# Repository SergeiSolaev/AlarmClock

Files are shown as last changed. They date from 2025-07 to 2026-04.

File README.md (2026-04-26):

<h1 align="center"> Часы-будильник</h1>
<p align="center">
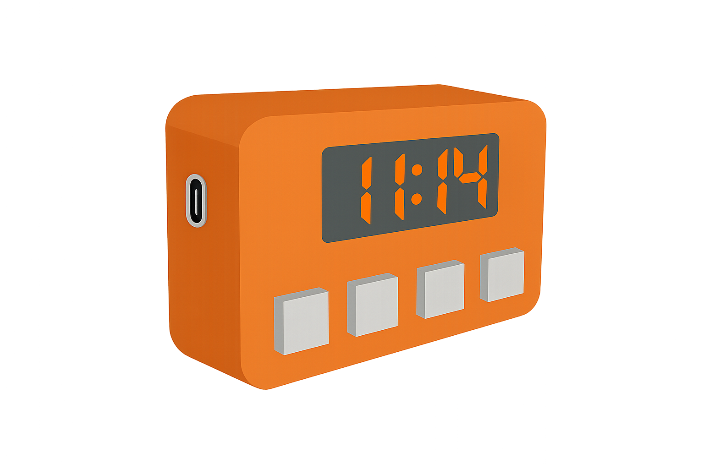
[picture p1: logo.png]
  
</p>
<p align="center">
  
</p>

## Описание проекта

Данный проект представляет собой автономный **умный будильник** на базе **Atmega328P-AU**, оснащённый модулем реального времени **DS3231**, MP3‑плеером **DFPlayer Mini**, семисегментным индикатором **TM1637**, вибромотором и системой энергосбережения. Устройство рассчитано на работу от аккумулятора и может использоваться как настольный или переносной будильник.

Проект ориентирован на низкое энергопотребление, удобное управление кнопками и расширенный функционал: музыка, вибрация, отложенный сигнал, индикация напряжения батареи и автоматическая регулировка яркости.

## ПО использованное при создании проекта
В проекте использовал следующее ПО:
- проектирование печатной платы `EasyEDA`
- проектирование корпуса `FreeCAD`
- написание кода `VSCode`, язык `Arduino C`
---

## Основные возможности

* Отображение текущего времени (RTC DS3231)
* Отображение даты и температуры
* Настраиваемый будильник
* Режим «Вздремнуть» (откладывание будильника)
* Таймер обратного отсчёта
* Звуковой сигнал (MP3) + вибрация
* Проигрывание музыки
* Регулировка громкости
* Автоматическая регулировка яркости по датчику освещённости
* Контроль напряжения аккумулятора
* Индикация разряда батареи
* Режим глубокого сна для экономии энергии
* Встроенный фонарик (LED)

---

## Аппаратная часть

### Основные компоненты

* **ATmega328P-AU** - микроконтроллер
* **RTC DS3231** — модуль реального времени
* **TM1637** — 4‑разрядный семисегментный индикатор
* **DFPlayer Mini** — MP3‑плеер для сигнала будильника и музыки
* **Вибромотор**
* **Светодиод** — режим фонарика
* **Фоторезистор** — датчик освещённости
* **Кнопки управления (4 шт.)**
* **Li‑Ion / Li‑Po аккумулятор**

### Питание и зарядка

Питание устройства осуществляется от аккумулятора.

*  Используется модуль **TP4056**
* Зарядка через разъём **USB Type‑C**
* Возможность одновременной зарядки и работы устройства

---

## Управление кнопками

| Кнопка | Действие |
| --- | --- |
| BTN1 | Вход / выход из меню, остановка будильника, выход из режима сна
| BTN2 | Показ температуры и даты. Подтверждение, сон (долгое нажатие) 
| BTN3 | Показ напряжения, отложить сигнал, уменьшение значений |
| BTN4 | Фонарик, отложить сигнал, увеличение значений |

---

## Меню

Меню вызывается коротким нажатием **BTN1**:

* **CLO** — установка времени
* **ALr** — включение / настройка будильника
* **LOUd** — установка громкости будильника
* **PLAY** — режим музыкального плеера
* **Chro** — таймер обратного отсчёта

Навигация осуществляется кнопкой **BTN4**, подтверждение — **BTN2**.

---

## Энергосбережение

* Отключение неиспользуемых периферийных модулей MCU
* Глубокий сон (**POWERDOWN_SLEEP**)
* Пробуждение по кнопке или сигналу RTC 

---

## Используемые библиотеки

* `RTClib`
* `DFPlayerMini_Fast`
* `GyverTM1637`
* `GyverPower`
* `EncButton`
* `EEPROM`

---

## Примечания

* Перед использованием рекомендуется откалибровать измерение напряжения батареи (см. комментарии в функции `voltageMeasure()`)
* Для установки времени с компьютера необходимо раскомментировать строку установки RTC в `setup()`
* Инструкцию по загрузке mp3 файлов на карту памяти см. в [/mp3/README.md](./mp3/README.md)

---

## Проектные файлы
### 3D модели корпуса
- [3d модель для FreeCAD](./free_cad/enclosure.FCStd)
- [Основной корпус](./free_cad/box.stl)
- [Крышка](./free_cad/lid.stl)

### Файлы печатной платы
- [Схема принципиальная](./easy_eda/Alarm_clock.json)
- [Разводка платы](./easy_eda/PCB_Alarm_clock.json)

## Фотографии проекта
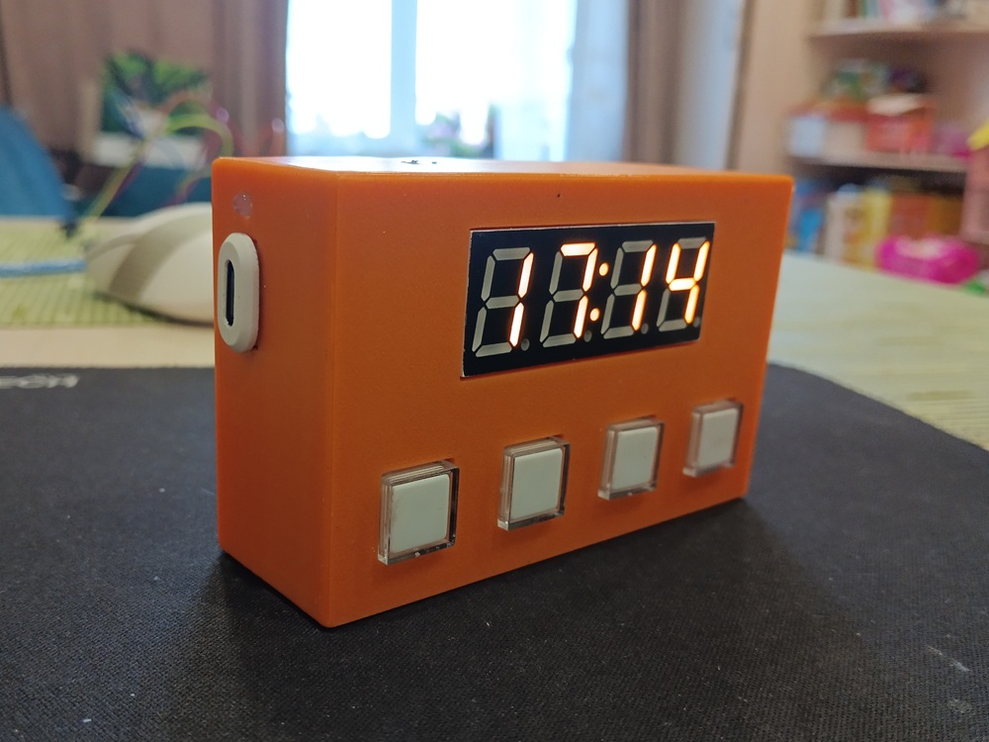
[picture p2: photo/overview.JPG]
Общий вид будильника
   
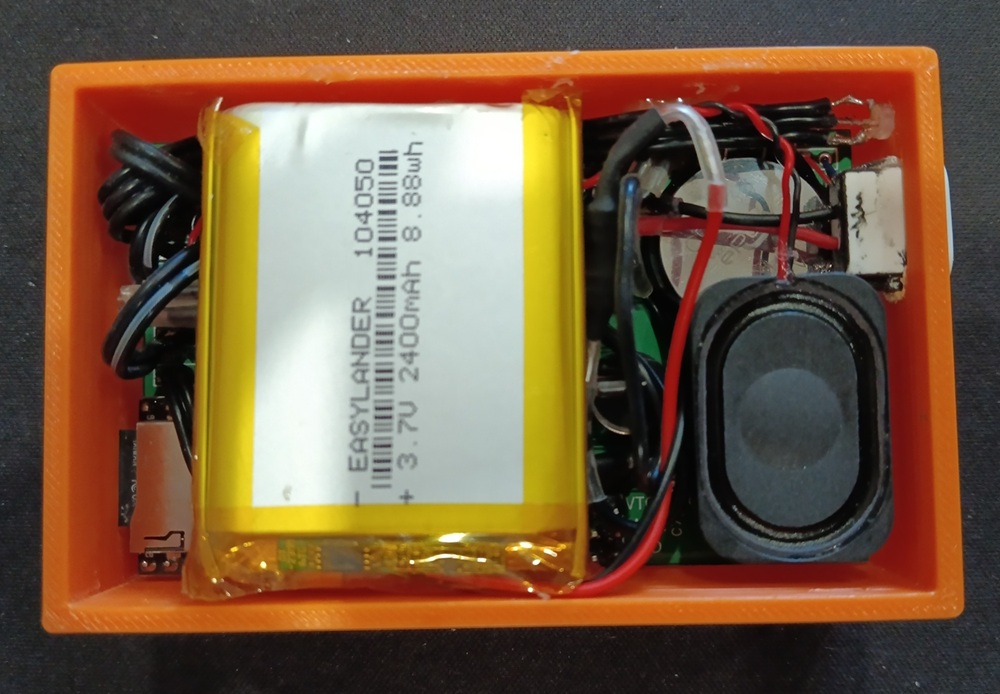
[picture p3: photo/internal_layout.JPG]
Внутренняя компоновка
   
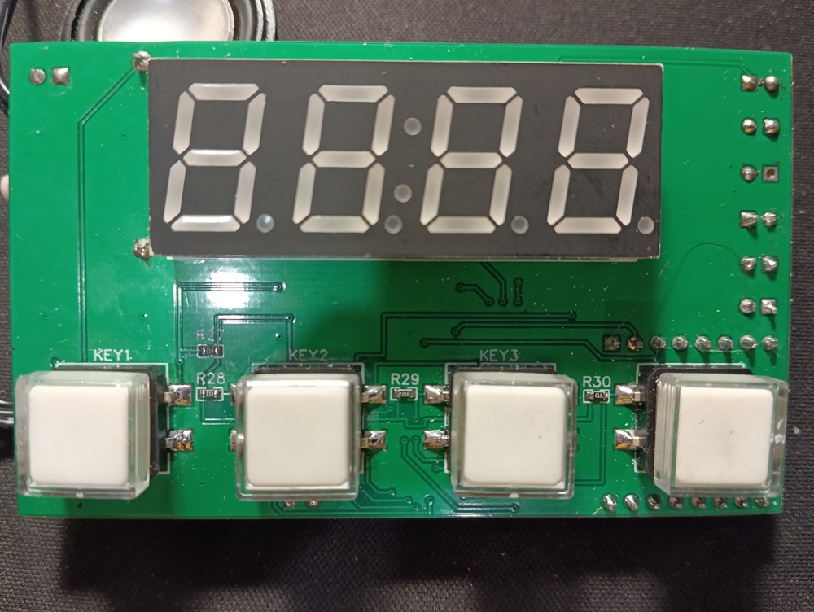
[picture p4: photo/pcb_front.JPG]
Плата будильника спереди
   
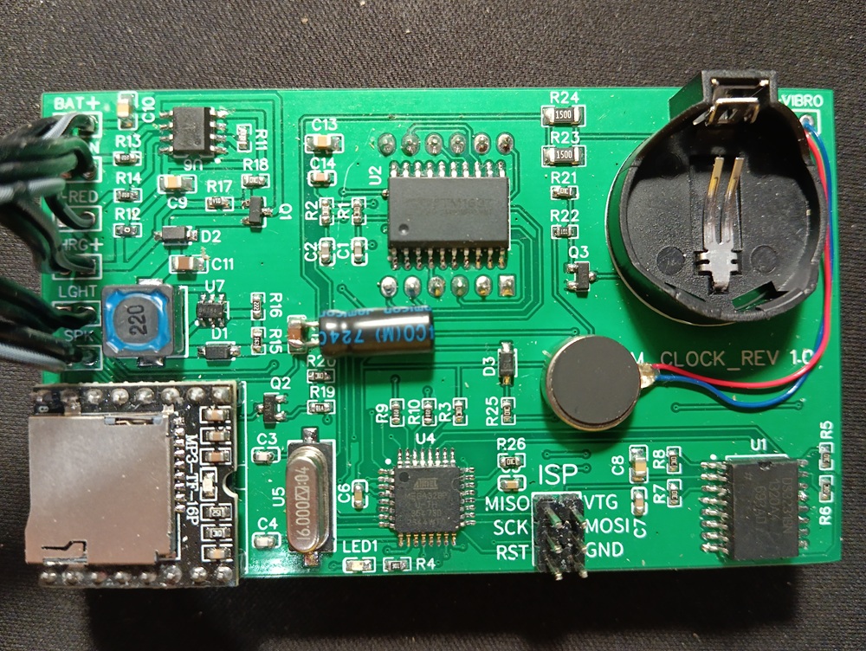
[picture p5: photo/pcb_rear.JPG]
Плата будильника сзади
 
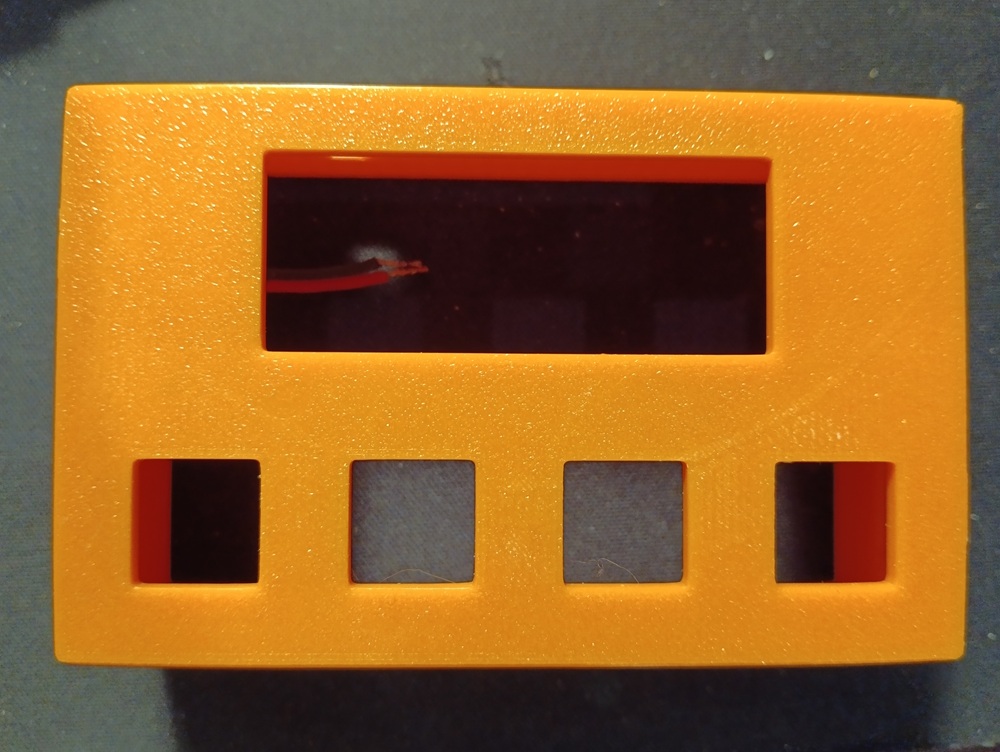
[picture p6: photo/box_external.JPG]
Корпус снаружи
   
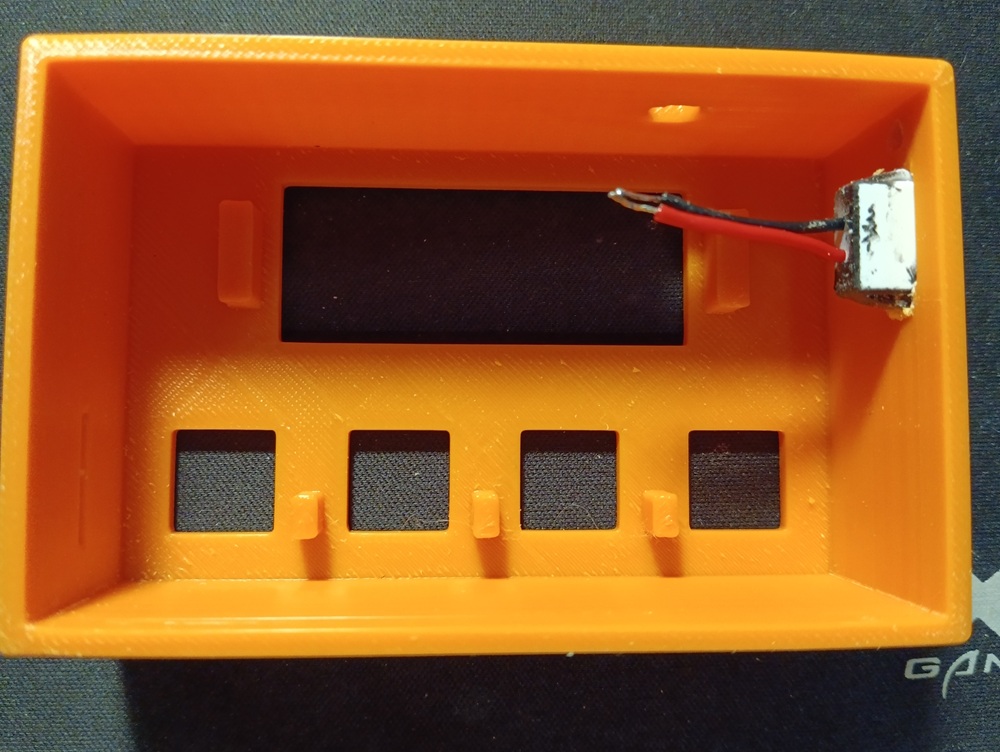
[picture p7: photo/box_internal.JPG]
Корпус внутри
   
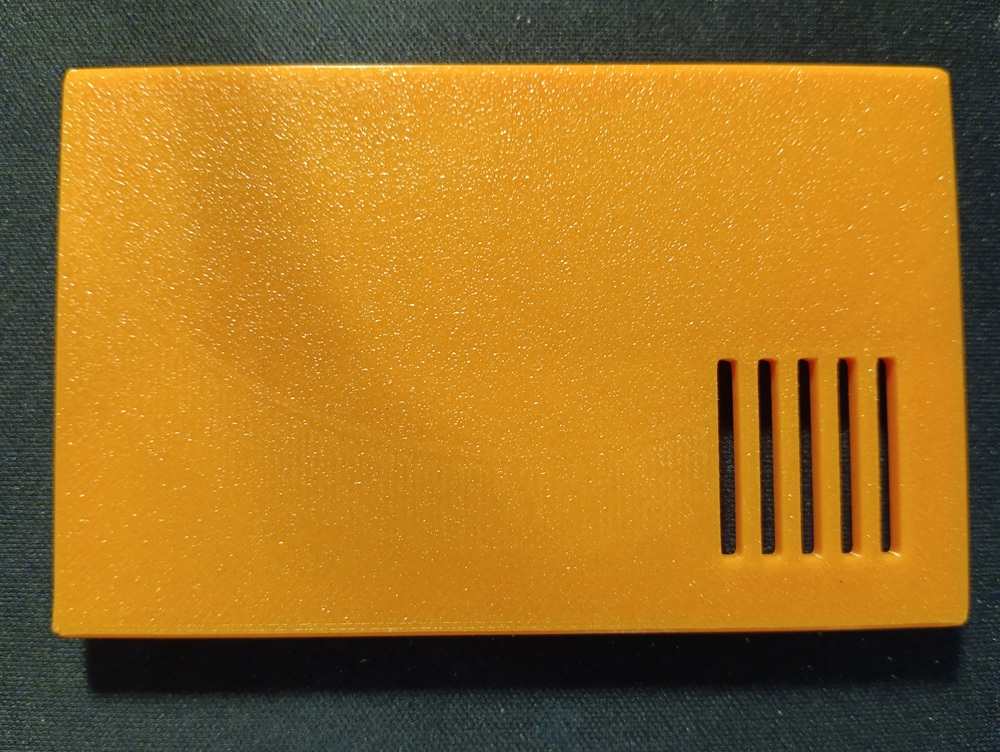
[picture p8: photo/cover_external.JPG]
Крышка снаружи
   
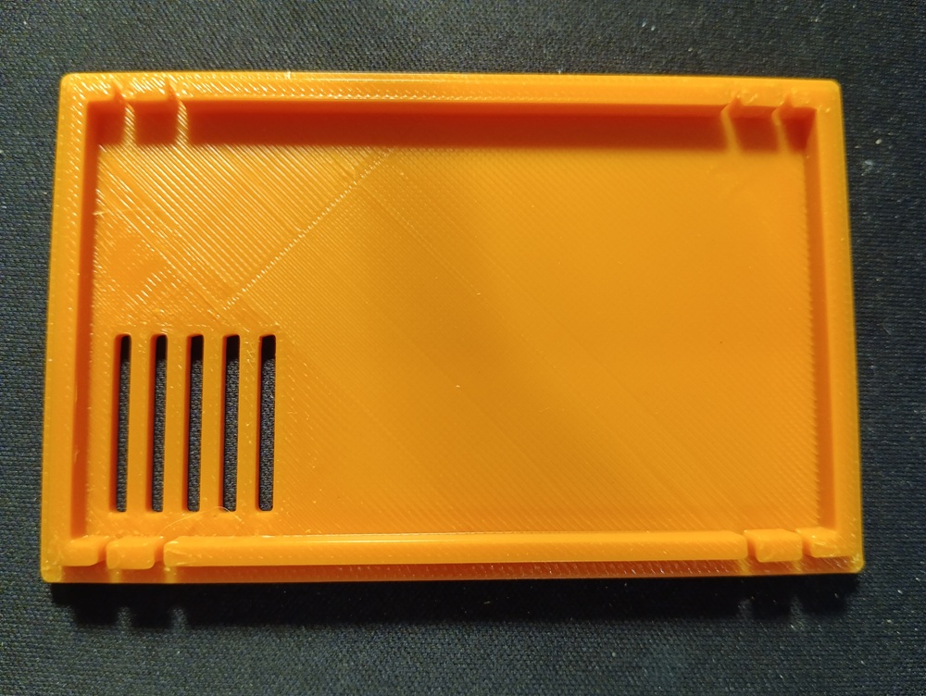
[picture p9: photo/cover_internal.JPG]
Крышка внутри
   

> Все файлы доступны в репозитории проекта. Для 3D печати рекомендуется использовать ABS пластик. Для загрузки скетча в микроконтроллер используется внутрисхемное программирвание. 

## Лицензия

Проект распространяется свободно и может быть использован, изменён и дополнен в учебных и личных целях.

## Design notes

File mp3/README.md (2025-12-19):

# Инструкция по загрузке аудиофайлов 

## Описание папки с аудиофайлами для DF Player Mini

В этой папке хранятся MP3-файлы, предназначенные для загрузки на карту памяти модуля воспроизведения музыки **DF Player Mini**

## Требования к файлам и карте памяти

- **Файловая система**:  
  Карта памяти должна быть отформатирована в **FAT16** или **FAT32**.

- **Имена файлов**:  
  Файлы должны быть названы в формате `0001.mp3`, `0002.mp3` и так далее.  

- **Расположение файлов**:  
  Все аудиофайлы должны быть загружены в папку `01` на карте памяти. Максимальное число файлов в папке `255`.

## Файл сигнала разряда батареи (отключено в v1.0.0)

В папке проекта находится файл:  
`0009_Battery_Discharge.mp3`  

Этот файл используется для воспроизведения сигнала при разрядке батареи.

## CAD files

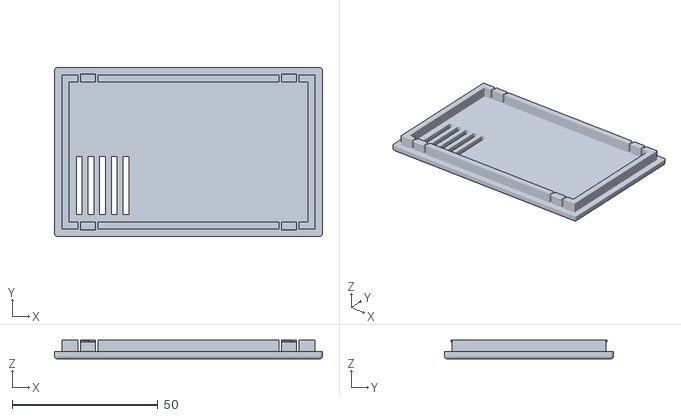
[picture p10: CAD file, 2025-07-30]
free_cad/lid.stl
92.0 x 58.0 x 6.50

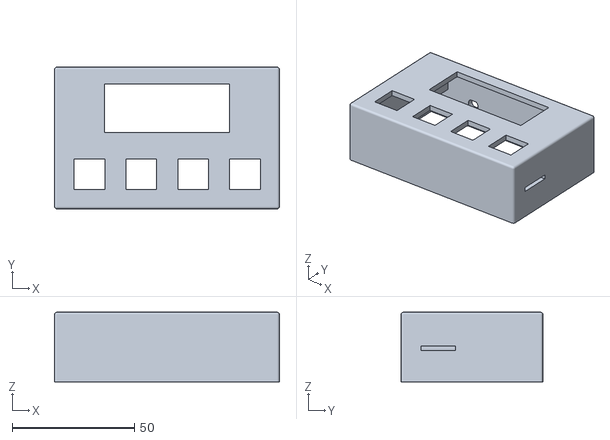
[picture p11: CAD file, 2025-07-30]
free_cad/box.stl
92.0 x 58.0 x 28.5

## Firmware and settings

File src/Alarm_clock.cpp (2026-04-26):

#include "Arduino.h"
#include "EEPROM.h"
#include "math.h"
#include "DFPlayerMini_Fast.h"
#include "RTClib.h"
#include "GyverTM1637.h"
#include "GyverPower.h"
#include "EncButton.h"

#define FW_VERSION "1.5.2"

// ===== HARDWARE =====

// Пины
#define BTN_1 2 // Pulup подтяжка(к "+" питания), когда нажата возвращает 0
#define BTN_2 10
#define BTN_3 4
#define BTN_4 5
#define CLK 6 // Подключение индикатора TM1637
#define DIO 7 // Подключение индикатора TM1637
#define VIBRO 8
#define MUSIC_MOSFET 9
#define LED 13
#define LIGHT_SENSOR A0
#define VOLTAGE A1

// Создаем объекты устройств
DFPlayerMini_Fast myMP3;
RTC_DS3231 rtc; // RTC DS3231 подключается к SDA – A4, SCL – A5
GyverTM1637 disp(CLK, DIO);

// Создаем объекты кнопок
Button btn1(BTN_1, INPUT_PULLUP, LOW);
Button btn2(BTN_2, INPUT_PULLUP, LOW);
Button btn3(BTN_3, INPUT_PULLUP, LOW);
Button btn4(BTN_4, INPUT_PULLUP, LOW);

// ===== SYSTEM TIMERS =====

uint32_t displayClockTimer;
uint32_t updateTimeTimer;
uint32_t vibroToggleTimer;
uint32_t batteryControlTimer;
uint32_t brightnessControlTimer;
uint32_t unblockMenuTimer;
uint32_t playMusicDisplayOfTimer;

// ===== CLOCK =====

bool clockOn = true;
bool secondsDots = false;

uint16_t year;
uint8_t month;
uint8_t day;
uint8_t hrs;
uint8_t min;
uint8_t sec;

// ===== ALARM =====

bool alarmOn = false; // Определяет включена ли функция будильньика
bool alarmOnDefault = false;
bool alarmSignal = false;
bool alarmMenuState = false;
bool alarmTriggered = false;
bool snoozeActive = false;

uint32_t alarmStartTime;
uint32_t alarmDuration = 60000;

uint8_t alarmHrs;
uint8_t alarmMin;
uint8_t alarmVolume;

uint8_t snoozeCount;
uint32_t snoozeStartTime;
uint32_t snoozeDuration = 300000;

// значения по умолчанию
uint8_t alarmHrsDefault = 12;
uint8_t alarmMinDefault = 0;
uint8_t alarmVolumeDefault = 20;

// ===== COUNTDOWN TIMER =====

bool timerActive = false;
bool timerFinished = false;
bool displayBlinking = false;
bool timerDisplayState = true;
bool timerInitialized = false;

uint32_t timerStartValue;    // начальное значение таймера в миллисекундах
uint32_t timerCurrentRemain; // оставшееся время
uint32_t timerPrevUpdate;    // время последнего обновления
uint32_t displayToggleTimer; // таймер для мигания дисплеем

// Значение таймера по умолчанию
uint32_t timerMinuteSet = 00;
uint32_t timerSecondSet = 00;

// ===== SIGNAL DEVICES =====

bool vibroToggle = true;
bool flashLightOn = false;
bool isPlaying = false;

// ===== POWER / BATTERY =====

bool batteryDischarge;

// ===== BRIGHTNESS CONTROL =====

int8_t currentBrightnessLevel = -1;

// ===== DISPLAY =====

// Преобразование символа цифры в код сегмента для передачи символа в функцию вывода на дисплей
// для показа версии
#define DIGIT_TO_SEG(x)              \
  ((x) == '0' ? _0 : (x) == '1' ? _1 \
                 : (x) == '2'   ? _2 \
                 : (x) == '3'   ? _3 \
                 : (x) == '4'   ? _4 \
                 : (x) == '5'   ? _5 \
                 : (x) == '6'   ? _6 \
                 : (x) == '7'   ? _7 \
                 : (x) == '8'   ? _8 \
                                : _9)

// Версия прошивки для показа
uint8_t fw_version[] = {
    _F,
    DIGIT_TO_SEG(FW_VERSION[0]),
    DIGIT_TO_SEG(FW_VERSION[2]),
    DIGIT_TO_SEG(FW_VERSION[4])};
// Сообщение "Зарядите батарею"
uint8_t chargeBattery[] = {_C, _H, _A, _r, _G, _E, _empty, _b, _A, _t, _t, _E, _r, _Y};

// ===== MAIN MENU =====
bool buttonsBlocked = false;
bool justWoke = false;
bool justWokeBlockMenu = false;
bool menuActive = false;
bool mainMenuActive = false;
int8_t mainMenuItem = 0;

// ===== SET TIME MENU =====
uint8_t clockMinTmp;
uint8_t clockHrsTmp;
uint8_t clockDate;
uint8_t clockMonth;
int clockYear;
bool setTimeMenuActive = false;
bool setTimeMenuDateTimeUpdate = false;
uint8_t setTimeStage = 0;

// ===== ALARM ON/OFF MENU =====
bool alarmOnOffMenuActive = false;

// ===== SET ALARM MENU =====
bool setAlarmDateTimeUpdated;
bool setAlarmActive;

uint8_t alarmHrsTmp;
uint8_t alarmMinTmp;

// ===== SET TIMER MENU =====
bool setTimerInitialized = false;
bool setTimerActive = false;
int timerMinuteSetTmp;
int timerSecondSetTmp;

// ===== SET VOLUME MENU =====
bool setVolumeActive = false;
bool setVolumeInitialized = false;
uint8_t setVolumeTmp;
uint32_t setVolTimer;

// ===== PLAY MUSIC MENU =====
bool playMusicMenuActive = false;
int8_t playMusicMenuItem = 0;

// ===== SET VOLUME MUSIC =====
bool setVolumeMusicActive = false;
bool setVolumeMusicInitialized = false;
uint8_t currentMusicVolume = 20;
uint8_t setVolumeMusicTmp;

//     BUTTON HOLD CHANGING
uint32_t lastHourChangeTime = 0;
uint32_t lastMinuteChangeTime = 0;
uint16_t INITIAL_DELAY = 500;   // Начальная задержка перед первым изменением
uint16_t CHANGE_INTERVAL = 500; // Интервал между изменениями

// ===== Прототипы функций =====
void initializeClock();
void pinsConfig();
void powerConfig();
void buttonConfig();
void testVibro();
void enterSleepMode();
void wakeUp();
void updateButtons();
void updateDateTime();
void displayClock(byte hrs, byte min);
void onAlarmInterrupt();
void activateAlarm();
void snoozeButton();
void alarmStopButton();
void alarmStopTime();
void runCountDownTimer();
void brightnessControl();
double voltageMeasure();
void showVoltage(double voltage);
void batteryControl(double voltage);
void showDate();
void startAlarm();
void stopAlarm();
void startVibro();
void stopVibro();
void menu();
void alarmOnOffMenu();
void setAlarm();
void setTime();
void setTimer();
void setVolume();
void playMusicMenu();
void playMusic();
void previousTrack();
void nextTrack();
void stopMusic();
void setVolumeMusic();
void flashLight();
bool isLeapYear(uint16_t yearToCheck);
uint8_t getDaysInMonth(uint16_t yearToCheck, uint8_t monthToCheck);
bool isValidDate(uint16_t yearToCheck, uint8_t monthToCheck, uint8_t dayToCheck);
void normalizeClockDate();

void setup()
{
  initializeClock();
  pinsConfig();
  powerConfig();
  buttonConfig();
  attachInterrupt(1, onAlarmInterrupt, FALLING); // Подключаем прерывания для включения от сигнала DS3231
  testVibro();
  disp.displayByte(fw_version);
  delay(1500);
}

void loop()
{

  if (justWoke)
  {
    unblockMenuTimer = millis();
    justWoke = false;
    detachInterrupt(0); // Отключаем прерывания, которые срабатывают при нажатии кнопки 1
  }

  // Задержка на некоторое время, что-бы после нажатия кнопок отключения будильника
  // не происходил мгновенный вход в меню или активация других функций
  // привязанных к той или иной кнопке
  // Так-же работает при нажатие кнопки для выхода из спящего режима.
  if (millis() - unblockMenuTimer > 250)
  {
    buttonsBlocked = false;
  }

  updateButtons();

  // Данное условие обеспечивает включение звукового сигнала.
  if (alarmTriggered)
  {
    activateAlarm();
    alarmTriggered = false;
  }

  // Если будильник сработал блокируем все функции кнопок.
  // Ждём нажатие кнопок для остановки будильника или для откладывания или остановки по времени.
  if (alarmSignal)
  {
    buttonsBlocked = true;
    alarmStopButton();
    alarmStopTime();
    snoozeButton();
    // После 30 секунд сработки будильника включаем вибрацию.
    if (alarmSignal && (millis() - alarmStartTime > 30000))
    {
      startVibro();
    }
  }

  // Если активировали режим "Вздремнуть" то ждём 5 минут и запускаем будильник снова.
  if (snoozeActive)
  {
    if (millis() - snoozeStartTime > snoozeDuration)
    {
      activateAlarm();
      snoozeStartTime = millis();
      snoozeCount = snoozeCount + 1;
    }
  }

  if (mainMenuActive)
  {
    menu();
  }

  if (setTimeMenuActive)
  {
    setTime();
  }

  if (alarmOnOffMenuActive)
  {
    alarmOnOffMenu();
  }

  if (setAlarmActive)
  {
    setAlarm();
  }

  if (setTimerActive)
  {
    setTimer();
  }

  if (timerActive)
  {
    runCountDownTimer();
  }

  if (setVolumeActive)
  {
    setVolume();
  }

  if (playMusicMenuActive)
  {
    playMusicMenu();
  }

  if (setVolumeMusicActive)
  {
    setVolumeMusic();
  }

  // Обновление времени из rtc модуля DS3231
  // Периодичность раз в секунду
  if (millis() - updateTimeTimer > 1000)
  {
    updateDateTime();
    updateTimeTimer = millis();
  }

  // Показ времени на индикаторе
  if (millis() - displayClockTimer > 500)
  {
    if (!menuActive && !timerActive)
    {
      displayClockTimer = millis();
      displayClock(hrs, min);
    }
  }

  // Регулировка яркости
  if (millis() - brightnessControlTimer > 500)
  {
    brightnessControl();
  }

  // Контролируем состояние батареи раз в пять минут
  if (millis() - batteryControlTimer > 300000)
  {
    batteryControl(voltageMeasure());
    batteryControlTimer = millis();
  }

  // Вызов меню настроек времени и будильника (короткое нажатие BTN_1)
  if (btn1.click() && !buttonsBlocked && !menuActive)
  {
    menuActive = true;
    mainMenuActive = true;
  }

  // Показ температуры (встроенный в DS3231 датчик)
  // Показ даты
  if (btn2.click() && !buttonsBlocked && !menuActive)
  {
    showDate();
  }

  // Выключение отображения часов и уход в сон (удержание BTN_2)
  if (btn2.hold() && !buttonsBlocked && !menuActive)
  {
    clockOn = false;
  }

  // Показать напряжение батареи (короткое нажатие BTN_3)
  if (btn3.click() && !buttonsBlocked && !menuActive)
  {
    showVoltage(voltageMeasure());
  }

  // Включение фонарика (короткое нажатие BTN_4)
  if (btn4.click() && !buttonsBlocked && !menuActive)
  {
    flashLight();
  }

  // Проверка условий для засыпания. Если выполнено, то засыпаем.
  enterSleepMode();
}

// Инициализация устройств и загрузка настроек
void initializeClock()
{
  Serial.begin(9600);
  if (EEPROM.read(0) == 255)
  {                                    // 255 это значение записанное в ячейке EEPROM по умолчанию в ардуино
    EEPROM.update(0, alarmHrsDefault); // Обновляем значение ячейки на дефолтное время срабатывания будильника
  }
  if (EEPROM.read(1) == 255)
  {
    EEPROM.update(1, alarmMinDefault);
  }
  if (EEPROM.read(2) == 255)
  {
    EEPROM.update(2, alarmOnDefault);
  }
  if (EEPROM.read(3) == 255)
  {
    EEPROM.update(3, alarmVolumeDefault);
  }
  rtc.begin();
  rtc.adjust(DateTime(F(__DATE__), F(__TIME__))); // Раскоментировать строку для установки времени часов с компьютера
  rtc.clearAlarm(1);
  alarmHrs = EEPROM.read(0);
  alarmMin = EEPROM.read(1);
  alarmOn = EEPROM.read(2);
  alarmVolume = EEPROM.read(3);
  alarmMenuState = alarmOn;
  myMP3.begin(Serial, true);
  disp.clear();
  disp.brightness(7); // Яркость, 0 - 7 (минимум - максимум)
  updateDateTime();
  randomSeed(analogRead(A3)); // Считать значения (наводки) на неподключеном входе А3
                              // для формирования рандомной последовательности чисел
}

// Конфигурация пинов.
void pinsConfig()
{
  // Пины кнопок настраиваются автоматически в конструкторах EncButton
  pinMode(VIBRO, OUTPUT);
  pinMode(MUSIC_MOSFET, OUTPUT);
  pinMode(LED, OUTPUT);
  pinMode(LIGHT_SENSOR, INPUT);
  pinMode(VOLTAGE, INPUT);
}

// Настройка энергосбережения
void powerConfig()
{
  power.autoCalibrate();                                    // автоматическая калибровка
  power.hardwareDisable(PWR_SPI | PWR_TIMER1 | PWR_TIMER2); // отключаем неиспользуемые модули МК
  power.setSleepMode(POWERDOWN_SLEEP);                      // устанавливаем режим сна в который будем уходить
}

// Настройка кнопок
void buttonConfig()
{

  // Настраиваем кнопки (таймаут удержания 3 секунды для длинного нажатия)
  btn1.setHoldTimeout(2000);
  btn2.setHoldTimeout(2000);
  btn3.setHoldTimeout(2000);
  btn4.setHoldTimeout(2000);

  // Устанавливаем короткий таймаут антидребезга для быстрого реагирования
  btn1.setDebTimeout(30); // 30 мс вместо стандартных 50 мс
  btn2.setDebTimeout(30);
  btn3.setDebTimeout(30);
  btn4.setDebTimeout(30);

  // Устанавливаем короткий таймаут ожидания кликов (для быстрых повторных нажатий)
  btn1.setClickTimeout(300); // 150 мс вместо стандартных 500 мс
  btn2.setClickTimeout(300);
  btn3.setClickTimeout(300);
  btn4.setClickTimeout(300);
}

// Тест вибрации
void testVibro()
{
  digitalWrite(VIBRO, HIGH);
  delay(200);
  digitalWrite(VIBRO, LOW);
  delay(100);
  digitalWrite(VIBRO, HIGH);
  delay(100);
  digitalWrite(VIBRO, LOW);
}

// Вход в режим энергосбережения
void enterSleepMode()
{
  if (!clockOn && !alarmSignal && !isPlaying && !flashLightOn && !snoozeActive)
  {
    disp.clear();
    disp.point(false);
    buttonsBlocked = true;
    attachInterrupt(0, wakeUp, FALLING); // Включаем прерывания для включения от кнопки
    delay(1000);
    power.sleep(SLEEP_FOREVER);
  }
}

// Обработчик прерывания от кнопки 1
void wakeUp()
{
  clockOn = true;
  justWoke = true;
}

// Получение даты и времени из rtc DS3231
void updateDateTime()
{
  DateTime now = rtc.now();
  year = now.year();
  month = now.month();
  day = now.day();
  hrs = now.hour();
  min = now.minute();
  sec = now.second();
}

bool isLeapYear(uint16_t yearToCheck)
{
  return (yearToCheck % 4 == 0 && yearToCheck % 100 != 0) || (yearToCheck % 400 == 0);
}

uint8_t getDaysInMonth(uint16_t yearToCheck, uint8_t monthToCheck)
{
  if (monthToCheck < 1 || monthToCheck > 12)
  {
    return 31;
  }

  if (monthToCheck == 2)
  {
    return isLeapYear(yearToCheck) ? 29 : 28;
  }

  if (monthToCheck == 4 || monthToCheck == 6 || monthToCheck == 9 || monthToCheck == 11)
  {
    return 30;
  }

  return 31;
}

bool isValidDate(uint16_t yearToCheck, uint8_t monthToCheck, uint8_t dayToCheck)
{
  if (monthToCheck < 1 || monthToCheck > 12)
  {
    return false;
  }

  uint8_t maxDays = getDaysInMonth(yearToCheck, monthToCheck);
  return dayToCheck >= 1 && dayToCheck <= maxDays;
}

void normalizeClockDate()
{
  uint8_t maxDays = getDaysInMonth(clockYear, clockMonth);

  if (clockDate < 1)
  {
    clockDate = 1;
  }

  if (clockDate > maxDays)
  {
    clockDate = maxDays;
  }
}

// Опрос кнопок
void updateButtons()
{
  btn1.tick();
  btn2.tick();
  btn3.tick();
  btn4.tick();
}

// Отображение времени на семисегметном индикаторе
void displayClock(byte hrs, byte min)
{
  if (clockOn)
  {
    disp.displayClock(hrs, min); // Выводим время функцией часов
    secondsDots = !secondsDots;
    disp.point(secondsDots); // Вкл/выкл точки
  }
  if (!clockOn)
  {
    disp.clear();
    disp.point(false);
  }
}

// Обработчик прерывания от будильника RTC DS3231
void onAlarmInterrupt()
{
  snoozeCount = 0;
  alarmTriggered = true;
}

// Будильник
void activateAlarm()
{
  if (alarmOn && !alarmSignal)
  {
    alarmSignal = true;
    clockOn = true;
    alarmStartTime = millis();
    startAlarm();
  }
}

// Установка таймера
void setTimer()
{

  if (!setTimerInitialized)
  {
    timerMinuteSetTmp = timerMinuteSet;
    timerSecondSetTmp = timerSecondSet;
    setTimerInitialized = true;
  }

  uint32_t currentTime = millis();

  // Уменьшение минут при клике кнопки 3 (однократное нажатие)
  if (btn3.click())
  {
    timerMinuteSetTmp = timerMinuteSetTmp - 1;
    if (timerMinuteSetTmp < 0)
    {
      timerMinuteSetTmp = 99;
    }
  }
  // Уменьшение минут при удержании кнопки 3
  if (btn3.pressing())
  {
    uint16_t pressDuration = btn3.pressFor();
    if (pressDuration >= INITIAL_DELAY)
    {
      if (lastMinuteChangeTime == 0 || (currentTime - lastMinuteChangeTime >= CHANGE_INTERVAL))
      {
        timerMinuteSetTmp = timerMinuteSetTmp - 1;
        if (timerMinuteSetTmp < 0)
        {
          timerMinuteSetTmp = 99;
        }
        lastMinuteChangeTime = currentTime;
      }
    }
  }
  // Увеличение минут при клике кнопки 4 (однократное нажатие)
  if (btn4.click())
  {
    timerMinuteSetTmp = (timerMinuteSetTmp + 1) % 99;
  }
  // Увеличение минут при удержании кнопки 4
  if (btn4.pressing())
  {
    uint16_t pressDuration = btn4.pressFor();
    if (pressDuration >= INITIAL_DELAY)
    {
      if (lastMinuteChangeTime == 0 || (currentTime - lastMinuteChangeTime >= CHANGE_INTERVAL))
      {
        timerMinuteSetTmp = (timerMinuteSetTmp + 1) % 99;
        lastMinuteChangeTime = currentTime;
      }
    }
  }
  // Подтверждение установки
  if (btn2.click())
  {
    timerMinuteSet = timerMinuteSetTmp;
    timerSecondSet = timerSecondSetTmp;
    setTimerActive = false;
    timerActive = true;
    timerInitialized = false;
    disp.point(false);
    disp.displayByte(_S, _t, _r, _t);
    delay(500);
    return;
  }
  if (btn1.click()) // Выход из меню
  {
    disp.point(false);
    disp.displayByte(_E, _S, _C, _empty);
    setTimerActive = false;
    mainMenuActive = true;
    delay(1000);
    return;
  }
  // Отображение текущего времени будильника
  disp.displayClock(timerMinuteSetTmp, timerSecondSetTmp);
  disp.point(true);
  delay(50);
}

// Таймер
void runCountDownTimer()
{
  if (!timerInitialized)
  {
    timerStartValue = (timerMinuteSet * 60UL + timerSecondSet) * 1000UL; // начальное значение таймера в миллисекундах
    timerCurrentRemain = timerStartValue;                                // оставшееся время
    timerPrevUpdate = millis();                                          // время последнего обновления
    displayToggleTimer = millis();                                       // таймер для мигания дисплеем
    displayClockTimer = millis();
    timerFinished = false;
    displayBlinking = false;
    timerDisplayState = true;
    secondsDots = true;
    timerInitialized = true;
  }

  uint32_t currentTime = millis();

  // Обработка кнопки 1: Выход из таймера (до окончания)
  if (btn1.click() && !timerFinished)
  {
    timerActive = false;
    timerInitialized = false;
    mainMenuActive = true;
    disp.point(false);
    disp.displayByte(_E, _S, _C, _empty);
    delay(1000);
    return;
  }

  // Обработка длинного нажатия кнопки 2: Вкл/Выкл дисплея
  if (btn2.hold())
  {                     // Используем hold() для длинного нажатия (настроен на 2 сек)
    if (!timerFinished) // Если таймер еще не закончился
    {
      timerDisplayState = !timerDisplayState; // переключаем состояние отображения часов
      if (timerDisplayState)
      {
        disp.displayClock(timerCurrentRemain / 60000, (timerCurrentRemain % 60000) / 1000);
        disp.point(true); // восстанавливаем точки после включения
      }
      else
      {
        disp.clear();
        disp.point(false);
      }
    }
    // Если таймер закончился, длинное нажатие 2 не влияет на вкл/выкл,
    // только короткое нажатие останавливает сигнал.
  }

  // Обработка короткого нажатия кнопки 2: Включить дисплей (если он был выключен)
  if (btn2.click() && !timerDisplayState && !timerFinished)
  { // Если дисплей выключен и таймер не окончен
    timerDisplayState = true;
    disp.displayClock(timerCurrentRemain / 60000, (timerCurrentRemain % 60000) / 1000);
    disp.point(true); // восстанавливаем точки
  }

  // Проверяем, прошла ли одна секунда для обновления таймера
  if (currentTime - timerPrevUpdate >= 1000 && !timerFinished)
  {
    timerCurrentRemain -= 1000; // уменьшаем оставшееся время на 1 секунду
    timerPrevUpdate = currentTime;

    // Проверяем, закончился ли таймер
    if (timerCurrentRemain <= 0)
    {
      timerCurrentRemain = 0; // убедимся, что не уйдёт в отрицательные значения
      timerFinished = true;
      displayBlinking = true; // включаем режим мигания
      startAlarm();
    }
  }

  // Обновляем отображение на индикаторе
  if (currentTime - displayClockTimer >= 500)
  {
    if (timerDisplayState && !timerFinished)
    {
      displayClockTimer = millis();
      byte mins = timerCurrentRemain / 60000;
      byte secs = (timerCurrentRemain % 60000) / 1000;
      displayClock(mins, secs);
    }
  }

  // Режим мигания дисплеем после окончания таймера
  if (displayBlinking)
  {
    if (currentTime - displayToggleTimer >= 1000) // каждую секунду
    {
      timerDisplayState = !timerDisplayState; // переключаем состояние
      if (timerDisplayState)
      {
        byte mins = timerCurrentRemain / 60000;
        byte secs = (timerCurrentRemain % 60000) / 1000;
        disp.displayClock(mins, secs);
        disp.point(true);
      }
      else
      {
        disp.clear();
        disp.point(false);
      }
      displayToggleTimer = currentTime; // обновляем таймер мигания
    }
  }

  // Обновление яркости
  if (currentTime - brightnessControlTimer >= 500 && clockOn)
  {
    brightnessControlTimer = millis();
    brightnessControl();
  }

  // Обработка остановки сигнала после окончания таймера
  // Стоп можно сделать по любой кнопке (кроме 2 hold), например, 1, 2 click, 3, 4
  if (timerFinished)
  {
    if (btn1.click() || btn2.click() || btn3.click() || btn4.click())
    {
      // Останавливаем звуковой сигнал
      stopAlarm();
      // Выходим из цикла
      timerActive = false;
      mainMenuActive = true;
      timerFinished = false; // сбрасываем флаг для следующего запуска
      displayBlinking = false;
      clockOn = true; // восстанавливаем отображение времени
      disp.clear();
      disp.point(false);
      return; // выходим из основного цикла таймера
    }
  }
}

// Откладывание сигнала будильника при нажатии кнопок 3 или 4
void snoozeButton()
{
  if (btn3.click() || btn4.click())
  {
    rtc.clearAlarm(1);
    alarmSignal = false;
    stopVibro();
    stopAlarm();
    unblockMenuTimer = millis();
    alarmStartTime = 0; // Сбрасываем таймер при остановке будильника
    disp.point(false);
    disp.displayByte(_S, _n, _o, _o);
    delay(1000);
    if (snoozeCount < 3)
    {
      snoozeActive = true;
      snoozeStartTime = millis(); // Запускаем таймер для snooze
    }
    if (snoozeCount > 3)
    {
      snoozeActive = false;
      // Уход в сон после всех повторов
      clockOn = false;
      enterSleepMode();
    }
  }
}

// Остановка сигнала будильника с кнопок 1 и 2
void alarmStopButton()
{
  if (btn1.click() || btn2.click())
  {
    unblockMenuTimer = millis();
    rtc.clearAlarm(1);
    alarmSignal = false;
    stopVibro();
    stopAlarm();
    alarmStartTime = 0; // Сбрасываем таймер при остановке будильника
    snoozeActive = false;
    disp.point(false);
    disp.displayByte(_S, _t, _o, _P);
    delay(1000);
  }
}
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

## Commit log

2025-07-30 Первая версия проекта
    [box.stl, lid.stl]
2025-07-30 Исправил README.md
2025-07-30 Исправил README.md, добавил отображение фотографий
2025-07-30 Настроил функцию batteryControl
2025-10-10 Отредактировал README.md
2025-11-29 Будильник срабатывает по прерываниям от RTC. Добавил глубокий сон для энергосбережения. Добавил функцию snooze
2025-11-29 В setVolume() изменил папку воспроизведения файла уровня громкости
2025-11-30 Добавил счётчик потовро для snooze. Срабатыыает 3 раза, потом часы уходят в сон
2025-11-30 Добавил показ температуры при нажатии на 2-ю кнопку
2025-11-30 Добавил показ даты при нажатии на вторую кнопку
2025-11-30 Пофиксил установку даты и времени при загрузке скетча с компа
2025-11-30 Скорректировал интервал показа температуры
2025-12-02 Отключил показ температуры и даты, т.к. некорректно работает возврат значений (1 или 2) при нажатии кнопок. Отключил воспроизведение звукового сигнала при разряде батареи, т.к. в данном мп3 модуле не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
2025-12-12 chore: обновил настройки platformio.ini
    Обновил ссылки для загрузки библиотек с github.
    Изменил настройки для загрузки скетча через Aduino as ISP.
2025-12-19 fix: изменения работы с кнопками
    - подключил библиотеку EncButton.h, переработал логику работы с кнопками
    - исправил(убрал) заход в меню при выходе из спящего режима по кнопке 1
    [Alarm_clock.cpp]
2025-12-19 docs: отредактировал README.md v1.0.0
    привёл В соответствие README.md к версии прошивки 1.0.0
2025-12-19 chore: добавил в отслеживание mp3/README.md
2025-12-19 docs: добавил инструкцию по загрузке аудиофайлов
2025-12-19 chore: загрузил файл сигнала разряда батареи
2026-02-21 hardware: обновил схему и плату
    1. Добавил конденсатор C15, что-бы запуск устройства был стабилен,
    без этого конденсатора просиходит перезагрузка часов, не хватает тока.
    2. Подключил кнопки к другим выводам, что-бы можно было использовать
    прерывания.
    3. Сделал площадки для припаивания перемычек в тех местах, где нет
    возможности проложить дорожки.
2026-02-21 feat: добавил новую функцию кнопок, resolves #1
    Теперь значения часов и минут изменяются
    при удержании кнопки 3 или 4 в меню настройки
    часов и будильника.
    [Alarm_clock.cpp]
2026-02-22 fix: неверное поведение кнопок, fixes #2
    Исправил проблему с мгновенным входом в меню после
    отключения сигнала будильника. Добавил задержку
    250 мс.
    [Alarm_clock.cpp]
2026-02-27 fix: Исправил ошибку входа в меню.
    Исправил ошибку входа в меню при нажатие кнопки 1
    при выходе из спящего режима.
    [Alarm_clock.cpp]
2026-02-27 fix: Исправил ошибку функции snoozeButton();
    Исправил ошибку активации фонарика и показа напряжения
    при нажатии кнопки 3 или 4 для активации функции
    "вздремнуть" при сработавшем будильнике.
    [Alarm_clock.cpp]
2026-02-27 chore: добавил логотип проекта для README.md
2026-02-27 docs: правка README.md
2026-02-27 docs: центровка изображений в README.md
2026-02-27 docs: центровка изображений README.md
2026-03-07 feat: Добавил таймер и небольшой рефакторинг
    Добавил функцию таймера
    Добавил показ версии прошивки при запуске
    вместо приветственного сообщения
    Небольшой рефакторинг кода
2026-03-09 fix: изменил пин для чтения шума рандомайзера
    [Alarm_clock.cpp]
2026-03-09 fix: исправил зависание таймера при 2-м запуске
    [Alarm_clock.cpp]
2026-03-09 fix: синхронизировал мигание точек с секундами
    Сделал мигание точек раз в секунду
    Изменил способ обновления яркости в timer()
    [Alarm_clock.cpp]
2026-03-09 feat: добавил показ даты и температуры
2026-03-09 feat: сделал показ версии прошивки в меню
2026-03-11 refactor: небольшой рефакторинг
    изменил наименование переменных и функций
    вынес опрос кнопок в отдельную функцию
    сгруппировал переменные
2026-03-26 feat: индикация режима отключения будильнка
    после нажатия кнопки stop или snooze выводится
    соответствующее текстовое оповещение
2026-03-26 feat: сделал переход в меню в обратную сторону
2026-03-28 feat: сделал неблокирующее главное меню, без while
2026-03-28 refactor: поправил форматирование кода
2026-03-30 feat: подготовка setTime() к уадлению while
2026-03-30 feat: сдела setTime неблокирующей (без while)
2026-03-30 refactor: сделал alarOnOff неблок (без while)
2026-04-01 refactor: сделал setAlarm неблок (без while)
2026-04-01 refactor: сделал setVolume неблокирующей
2026-04-04 refactor: убрал while из playMusicMenu()
2026-04-04 refactor: удалил while из setVolumeMusic
2026-04-04 refactor: убрал while из setTimer
2026-04-08 refactor: сделал runCountdownTimer() без while
2026-04-08 refactor: исправил версию, закрыл issue, closes #3
    [Alarm_clock.cpp]
2026-04-23 fix: исправил зависание таймера при отмене
    [Alarm_clock.cpp]
2026-04-26 feat: сделал установку даты с кнопок
2026-04-26 feat: сделал валидацию даты перед установкой
    проверку даты на правильность количества дней в месяце
    и на високосный год
2026-04-26 Обновил номер версии
2026-04-26 fix: удадлил показ температуры
    удалил показ температуры т.к. встроенный в модуль
    ds3231 датчик не точен(служит для термокомпенсации часов
    а не для точного измерения температуры.
    [Alarm_clock.cpp]
2026-04-26 feat: сделал гистерезис для подсветки
    сделал гистерезис для подстветки
    что-бы не индикатор не мерцал на границах
    перехода значения яркостиё
